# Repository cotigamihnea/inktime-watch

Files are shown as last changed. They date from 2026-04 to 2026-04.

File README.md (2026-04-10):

# InkTime Smartwatch - Proiect Hardware

Acesta este repository-ul oficial pentru dezvoltarea hardware a proiectului InkTime, un smartwatch bazat pe tehnologia E-Paper și procesorul nRF52840, optimizat pentru un consum redus de energie.

---

## 1. Diagramă Bloc

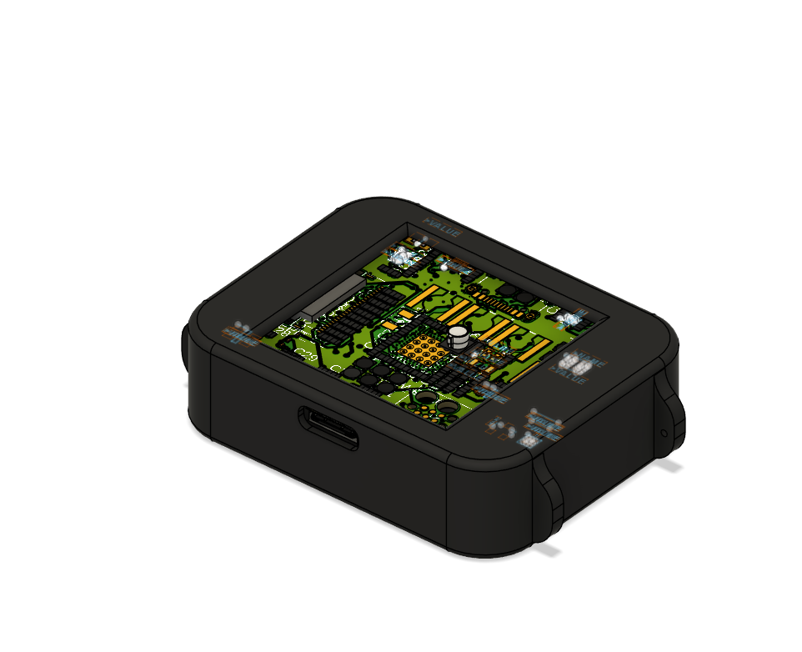
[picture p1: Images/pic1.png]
Diagrama Bloc


---

## 2. Bill of Materials (BOM) Principale

Mai jos sunt listate componentele integrate (IC) principale folosite în designul acestui smartwatch. Fișierul BOM complet cu toate componentele pasive (rezistențe, condensatoare) se găsește în folderul `Manufacturing`.

| Componentă / Modul | Rol în Sistem | JLC Parts Link | Datasheet |
| :--- | :--- | :--- | :--- |
| **nRF52840-QIAA** | Microcontroller Principal (BLE 5.0) | [C209930](https://jlcpcb.com/partdetail/Nordic_Semiconductor-nRF52840_QIAAR/C209930) | [Datasheet nRF52840](https://infocenter.nordicsemi.com/pdf/nRF52840_PS_v1.1.pdf) |
| **BQ25180YBGR** | Li-Ion Battery Charger (PMIC) | [C3005391](https://jlcpcb.com/partdetail/TexasInstruments-BQ25180YBGR/C3005391) | [Datasheet BQ25180](https://www.ti.com/lit/ds/symlink/bq25180.pdf) |
| **MAX17048G+T10** | Fuel Gauge (Monitorizare Baterie) | [C137599](https://jlcpcb.com/partdetail/Maxim_Integrated-MAX17048GT10/C137599) | [Datasheet MAX17048](https://datasheets.maximintegrated.com/en/ds/MAX17048-MAX17049.pdf) |
| **BMA421** | IMU / Accelerometru (Pedometer) | [C456073](https://jlcpcb.com/partdetail/Bosch-BMA421/C456073) | [Datasheet BMA421](https://www.bosch-sensortec.com/media/boschsensortec/downloads/datasheets/bst-bma421-fl000.pdf) |
| **503480-2400** | Conector Display E-Paper (24 pini) | [C265215](https://jlcpcb.com/partdetail/Molex-5034802400/C265215) | [Datasheet Molex](https://www.molex.com/pdm_docs/sd/5034802400_sd.pdf) |

---

## 3. Descrierea Funcționalității Hardware

Proiectul InkTime este gândit ca un wearable ultra-low-power. Arhitectura hardware este împărțită în următoarele module principale:

* **Unitatea de Procesare și Comunicație (nRF52840):** Este "creierul" plăcii. Acesta conține un nucleu ARM Cortex-M4F și un modul radio Bluetooth Low Energy (BLE 5.0). Microcontroller-ul gestionează toate perifericele și permite sincronizarea datelor cu un smartphone.
* **Afișajul (E-Paper Display):** Conectat printr-o interfață **SPI**, display-ul E-paper a fost ales pentru consumul său zero de energie în starea de repaus (consumă curent doar la refresh-ul ecranului). Circuitul său include o sursă de tensiune dedicată, cu o bobină și diode, comandată de un tranzistor DMG2305UX, pentru a-i asigura tensiunile specifice de operare.
* **Managementul Energiei (Power Management):** * **BQ25180:** Se ocupă de încărcarea sigură a bateriei Li-Po de la mufa USB (5V), setând curenți mici de încărcare adecvați bateriilor de smartwatch.
    * **MAX17048 (Fuel Gauge):** Citește tensiunea bateriei și calculează procentul (State of Charge - SoC) folosind algoritmul ModelGauge. Ambele comunică cu nRF-ul prin magistrala **I2C**.
* **Senzori și Haptic:** Accelerometrul **BMA421** este folosit pentru detectarea mișcării (ex: ridicarea mâinii pentru a aprinde ecranul) și numărarea pașilor, comunicând tot prin **I2C**. Pentru feedback tactil s-a integrat un driver haptic.
* **Considerații de Consum:** Designul este centrat pe eficiență. nRF52840 va sta majoritatea timpului în *Deep Sleep* (câțiva microamperi), trezindu-se doar la întreruperi generate de BMA421 (mișcare) sau la intervale regulate pentru a actualiza ecranul prin SPI.

---

## 4. Pinout nRF52840 (Alocarea Pinilor)

Microcontroller-ul comunică cu restul modulelor folosind interfețe digitale standardizate. Magistrala I2C este partajată pentru a economisi pini.

| Periferic / Modul | Pini nRF52840 Alocați | Interfață | Motiv / Funcție |
| :--- | :--- | :--- | :--- |
| **Magistrala I2C (Comună)** | `P0.11` (SDA), `P0.12` (SCL) | I2C | Folosită pentru BQ25180 (Charger), MAX17048 (Baterie) și BMA421 (IMU). I2C permite legarea mai multor senzori pe doar 2 pini fizici, reducând complexitatea rutării. |
| **BMA421 (Senzor Mișcare)**| `P0.13` (INT1) | GPIO | Pin de întrerupere pentru a „trezi” procesorul din sleep când utilizatorul face o mișcare bruscă. |
| **Display E-Paper** | `P1.01` (MOSI), `P1.02` (SCK), `P1.03` (CS) | SPI | Interfață de mare viteză unidirecțională pentru a trimite pixelii către ecran rapid. |
| **Control E-Paper** | `P1.04` (DC), `P1.05` (RST), `P1.06` (BUSY)| GPIO | Pini de control pentru stările ecranului (Data/Command, Reset și monitorizarea stării de Busy în timpul refresh-ului). |
| **Alimentare E-Paper** | `P0.06` | GPIO | Controlează tranzistorul care taie complet alimentarea ecranului când nu este folosit, salvând energie. |

*(Notă: Pinii exacți au fost aleși pentru a facilita cel mai scurt drum de rutare (Placement Optimization) pe PCB).*

---

## 5. Design Log & Renders

**Jurnal de Design:**
Proiectarea PCB-ului a presupus mai multe provocări:
1.  **Placement:** Componentele au fost grupate în "cartiere" logice: RF-ul sus în jurul antenei pentru a minimiza interferențele, IC-urile de Power Management lângă conectorul bateriei/USB, iar componentele digitale centralizate în jurul procesorului nRF52840.
2.  **Routing:** Datorită densității mari de pe o placă cu factor de formă mic (Smartwatch), am utilizat un mix de rutare manuală pentru traseele sensibile și Autorouter pentru optimizarea conexiunilor logice, obținând o rată de conectare excelentă pentru un sistem cu doar 2 straturi.

**Randări PCB:**
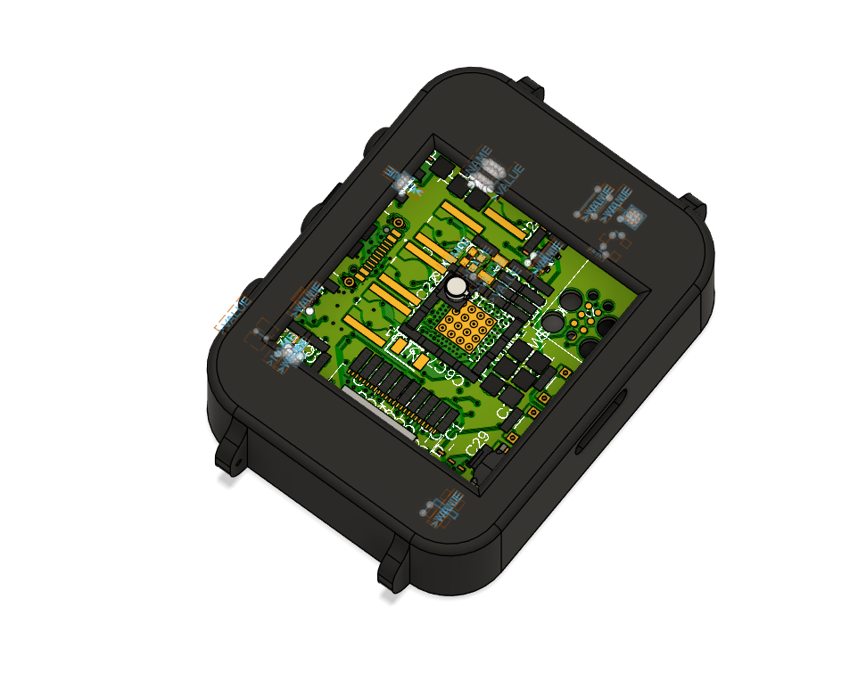
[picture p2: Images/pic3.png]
Top Render

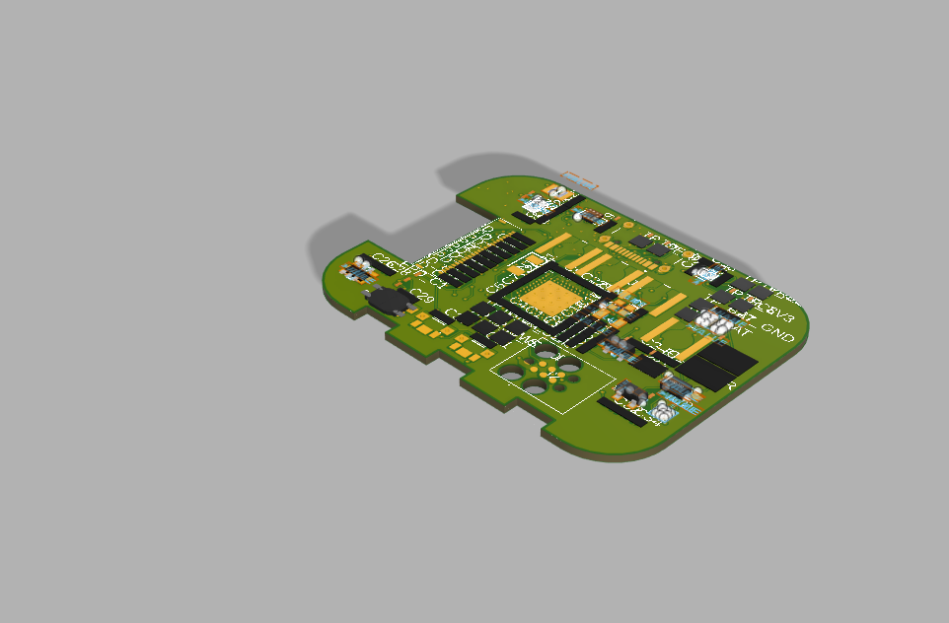
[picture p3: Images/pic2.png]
Bottom Render


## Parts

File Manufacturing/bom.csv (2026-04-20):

Part | Value | Device | Footprint Name | Detailed Description | ARROW_PART_NUMBER | ARROW_PRICE-STOCK | AVAILABILITY | CHECK_PRICES | COPYRIGHT | DESCRIPTION | DIGI-KEY_PART_NUMBER_1 | DIGI-KEY_PART_NUMBER_2 | DIGI-KEY_PART_NUMBER_3 | HEIGHT | JLCPCB | MANUFACTURER_NAME | MANUFACTURER_PART_NUMBER | MF | MFR_NAME | MOUSER_PART_NUMBER | MOUSER_PRICE-STOCK | MP | PACKAGE | POPULARITY | PRICE | PROD_ID | PURCHASE-URL | SNAPEDA_LINK | SPICEMODEL | SPICEPREFIX | TP_SIGNAL_NAME | VALUE
ANT1 | 2450AT18B100E_2450AT18B100E | 2450AT18B100E_2450AT18B100E | 2450AT18B100E_ANTC3216X140N | Antennas 2.45GHz ANTENNA | 2450AT18B100E | https://www.arrow.com/en/products/2450at18b100e/johanson-dielectrics?utm_currency=USD&region=nac |  |  |  | Antennas 2.45GHz ANTENNA |  |  |  | 1.4mm |  | JOHANSON TECHNOLOGY | 2450AT18B100E |  |  | 609-2450AT18B100E | https://www.mouser.co.uk/ProductDetail/Johanson-Technology/2450AT18B100E?qs=yCnrNFeXz%252Bh5MFsFIXGZGA%3D%3D
C1 | 12pF | ESP32_C6_LIBRARY_1_ESP32_WROVER_EAGLE-LTSPICE_CC0402 | ESP32_C6_LIBRARY_1_ESP32_WROVER_EAGLE-LTSPICE_C0402 | CAPACITOR, European symbol |  |  |  |  |  |  |  |  |  |  |  |  |  |  |  |  |  |  |  |  |  |  |  |  | NONE | C
C1-EP-DR | 10uF | ESP32_C6_LIBRARY_1_ESP32_WROVER_EAGLE-LTSPICE_CC0402 | ESP32_C6_LIBRARY_1_ESP32_WROVER_EAGLE-LTSPICE_C0402 | CAPACITOR, European symbol |  |  |  |  |  |  |  |  |  |  |  |  |  |  |  |  |  |  |  |  |  |  |  |  | NONE | C
C2 | 12pF | ESP32_C6_LIBRARY_1_ESP32_WROVER_EAGLE-LTSPICE_CC0402 | ESP32_C6_LIBRARY_1_ESP32_WROVER_EAGLE-LTSPICE_C0402 | CAPACITOR, European symbol |  |  |  |  |  |  |  |  |  |  |  |  |  |  |  |  |  |  |  |  |  |  |  |  | NONE | C
C2-EP-DR1 | 4.7uF/25V | ESP32_C6_LIBRARY_1_ESP32_WROVER_EAGLE-LTSPICE_CC0402 | ESP32_C6_LIBRARY_1_ESP32_WROVER_EAGLE-LTSPICE_C0402 | CAPACITOR, European symbol |  |  |  |  |  |  |  |  |  |  |  |  |  |  |  |  |  |  |  |  |  |  |  |  | NONE | C
C3 | 1pF | ESP32_C6_LIBRARY_1_ESP32_WROVER_EAGLE-LTSPICE_CC0402 | ESP32_C6_LIBRARY_1_ESP32_WROVER_EAGLE-LTSPICE_C0402 | CAPACITOR, European symbol |  |  |  |  |  |  |  |  |  |  |  |  |  |  |  |  |  |  |  |  |  |  |  |  | NONE | C
C4 | 1pF | ESP32_C6_LIBRARY_1_ESP32_WROVER_EAGLE-LTSPICE_CC0402 | ESP32_C6_LIBRARY_1_ESP32_WROVER_EAGLE-LTSPICE_C0402 | CAPACITOR, European symbol |  |  |  |  |  |  |  |  |  |  |  |  |  |  |  |  |  |  |  |  |  |  |  |  | NONE | C
C5 | 100nF | ESP32_C6_LIBRARY_1_ESP32_WROVER_EAGLE-LTSPICE_CC0402 | ESP32_C6_LIBRARY_1_ESP32_WROVER_EAGLE-LTSPICE_C0402 | CAPACITOR, European symbol |  |  |  |  |  |  |  |  |  |  |  |  |  |  |  |  |  |  |  |  |  |  |  |  | NONE | C
C6 | 4.7uF | ESP32_C6_LIBRARY_1_ESP32_WROVER_EAGLE-LTSPICE_CC0402 | ESP32_C6_LIBRARY_1_ESP32_WROVER_EAGLE-LTSPICE_C0402 | CAPACITOR, European symbol |  |  |  |  |  |  |  |  |  |  |  |  |  |  |  |  |  |  |  |  |  |  |  |  | NONE | C
C7 | 100nF | ESP32_C6_LIBRARY_1_ESP32_WROVER_EAGLE-LTSPICE_CC0402 | ESP32_C6_LIBRARY_1_ESP32_WROVER_EAGLE-LTSPICE_C0402 | CAPACITOR, European symbol |  |  |  |  |  |  |  |  |  |  |  |  |  |  |  |  |  |  |  |  |  |  |  |  | NONE | C
C8 | 100nF N.C. | ESP32_C6_LIBRARY_1_ESP32_WROVER_EAGLE-LTSPICE_CC0402 | ESP32_C6_LIBRARY_1_ESP32_WROVER_EAGLE-LTSPICE_C0402 | CAPACITOR, European symbol |  |  |  |  |  |  |  |  |  |  |  |  |  |  |  |  |  |  |  |  |  |  |  |  | NONE | C
C9 | 820pF | ESP32_C6_LIBRARY_1_ESP32_WROVER_EAGLE-LTSPICE_CC0402 | ESP32_C6_LIBRARY_1_ESP32_WROVER_EAGLE-LTSPICE_C0402 | CAPACITOR, European symbol |  |  |  |  |  |  |  |  |  |  |  |  |  |  |  |  |  |  |  |  |  |  |  |  | NONE | C
C10 | N.C. | ESP32_C6_LIBRARY_1_ESP32_WROVER_EAGLE-LTSPICE_CC0402 | ESP32_C6_LIBRARY_1_ESP32_WROVER_EAGLE-LTSPICE_C0402 | CAPACITOR, European symbol |  |  |  |  |  |  |  |  |  |  |  |  |  |  |  |  |  |  |  |  |  |  |  |  | NONE | C
C11 | 1pF | ESP32_C6_LIBRARY_1_ESP32_WROVER_EAGLE-LTSPICE_CC0402 | ESP32_C6_LIBRARY_1_ESP32_WROVER_EAGLE-LTSPICE_C0402 | CAPACITOR, European symbol |  |  |  |  |  |  |  |  |  |  |  |  |  |  |  |  |  |  |  |  |  |  |  |  | NONE | C
C12 | 100nF | ESP32_C6_LIBRARY_1_ESP32_WROVER_EAGLE-LTSPICE_CC0402 | ESP32_C6_LIBRARY_1_ESP32_WROVER_EAGLE-LTSPICE_C0402 | CAPACITOR, European symbol |  |  |  |  |  |  |  |  |  |  |  |  |  |  |  |  |  |  |  |  |  |  |  |  | NONE | C
C13 | N.C. | ESP32_C6_LIBRARY_1_ESP32_WROVER_EAGLE-LTSPICE_CC0402 | ESP32_C6_LIBRARY_1_ESP32_WROVER_EAGLE-LTSPICE_C0402 | CAPACITOR, European symbol |  |  |  |  |  |  |  |  |  |  |  |  |  |  |  |  |  |  |  |  |  |  |  |  | NONE | C
C14 | 4.7uF | ESP32_C6_LIBRARY_1_ESP32_WROVER_EAGLE-LTSPICE_CC0402 | ESP32_C6_LIBRARY_1_ESP32_WROVER_EAGLE-LTSPICE_C0402 | CAPACITOR, European symbol |  |  |  |  |  |  |  |  |  |  |  |  |  |  |  |  |  |  |  |  |  |  |  |  | NONE | C
C15 | 1.0uF | ESP32_C6_LIBRARY_1_ESP32_WROVER_EAGLE-LTSPICE_CC0402 | ESP32_C6_LIBRARY_1_ESP32_WROVER_EAGLE-LTSPICE_C0402 | CAPACITOR, European symbol |  |  |  |  |  |  |  |  |  |  |  |  |  |  |  |  |  |  |  |  |  |  |  |  | NONE | C
C16 | 47nF | ESP32_C6_LIBRARY_1_ESP32_WROVER_EAGLE-LTSPICE_CC0402 | ESP32_C6_LIBRARY_1_ESP32_WROVER_EAGLE-LTSPICE_C0402 | CAPACITOR, European symbol |  |  |  |  |  |  |  |  |  |  |  |  |  |  |  |  |  |  |  |  |  |  |  |  | NONE | C
C17 | 12pF | ESP32_C6_LIBRARY_1_ESP32_WROVER_EAGLE-LTSPICE_CC0402 | ESP32_C6_LIBRARY_1_ESP32_WROVER_EAGLE-LTSPICE_C0402 | CAPACITOR, European symbol |  |  |  |  |  |  |  |  |  |  |  |  |  |  |  |  |  |  |  |  |  |  |  |  | NONE | C
C18 | 12pF | ESP32_C6_LIBRARY_1_ESP32_WROVER_EAGLE-LTSPICE_CC0402 | ESP32_C6_LIBRARY_1_ESP32_WROVER_EAGLE-LTSPICE_C0402 | CAPACITOR, European symbol |  |  |  |  |  |  |  |  |  |  |  |  |  |  |  |  |  |  |  |  |  |  |  |  | NONE | C
C19 | 22uF | ESP32_C6_LIBRARY_1_ESP32_WROVER_EAGLE-LTSPICE_CC0402 | ESP32_C6_LIBRARY_1_ESP32_WROVER_EAGLE-LTSPICE_C0402 | CAPACITOR, European symbol |  |  |  |  |  |  |  |  |  |  |  |  |  |  |  |  |  |  |  |  |  |  |  |  | NONE | C
C20 | 4.7uF | ESP32_C6_LIBRARY_1_ESP32_WROVER_EAGLE-LTSPICE_CC0402 | ESP32_C6_LIBRARY_1_ESP32_WROVER_EAGLE-LTSPICE_C0402 | CAPACITOR, European symbol |  |  |  |  |  |  |  |  |  |  |  |  |  |  |  |  |  |  |  |  |  |  |  |  | NONE | C
C21 | 4.7uF | ESP32_C6_LIBRARY_1_ESP32_WROVER_EAGLE-LTSPICE_CC0402 | ESP32_C6_LIBRARY_1_ESP32_WROVER_EAGLE-LTSPICE_C0402 | CAPACITOR, European symbol |  |  |  |  |  |  |  |  |  |  |  |  |  |  |  |  |  |  |  |  |  |  |  |  | NONE | C
C22 | N.C. | ESP32_C6_LIBRARY_1_ESP32_WROVER_EAGLE-LTSPICE_CC0402 | ESP32_C6_LIBRARY_1_ESP32_WROVER_EAGLE-LTSPICE_C0402 | CAPACITOR, European symbol |  |  |  |  |  |  |  |  |  |  |  |  |  |  |  |  |  |  |  |  |  |  |  |  | NONE | C
C23 | 0.1uF | ESP32_C6_LIBRARY_1_ESP32_WROVER_EAGLE-LTSPICE_CC0402 | ESP32_C6_LIBRARY_1_ESP32_WROVER_EAGLE-LTSPICE_C0402 | CAPACITOR, European symbol |  |  |  |  |  |  |  |  |  |  |  |  |  |  |  |  |  |  |  |  |  |  |  |  | NONE | C
C24 | 10uF | ESP32_C6_LIBRARY_1_ESP32_WROVER_EAGLE-LTSPICE_CC0402 | ESP32_C6_LIBRARY_1_ESP32_WROVER_EAGLE-LTSPICE_C0402 | CAPACITOR, European symbol |  |  |  |  |  |  |  |  |  |  |  |  |  |  |  |  |  |  |  |  |  |  |  |  | NONE | C
C25 | 22uF | ESP32_C6_LIBRARY_1_ESP32_WROVER_EAGLE-LTSPICE_CC0402 | ESP32_C6_LIBRARY_1_ESP32_WROVER_EAGLE-LTSPICE_C0402 | CAPACITOR, European symbol |  |  |  |  |  |  |  |  |  |  |  |  |  |  |  |  |  |  |  |  |  |  |  |  | NONE | C
C26 | 820pF | ESP32_C6_LIBRARY_1_ESP32_WROVER_EAGLE-LTSPICE_CC0402 | ESP32_C6_LIBRARY_1_ESP32_WROVER_EAGLE-LTSPICE_C0402 | CAPACITOR, European symbol |  |  |  |  |  |  |  |  |  |  |  |  |  |  |  |  |  |  |  |  |  |  |  |  | NONE | C
C27 | 0.1uF | ESP32_C6_LIBRARY_1_ESP32_WROVER_EAGLE-LTSPICE_CC0402 | ESP32_C6_LIBRARY_1_ESP32_WROVER_EAGLE-LTSPICE_C0402 | CAPACITOR, European symbol |  |  |  |  |  |  |  |  |  |  |  |  |  |  |  |  |  |  |  |  |  |  |  |  | NONE | C
C28 | 820pF | ESP32_C6_LIBRARY_1_ESP32_WROVER_EAGLE-LTSPICE_CC0402 | ESP32_C6_LIBRARY_1_ESP32_WROVER_EAGLE-LTSPICE_C0402 | CAPACITOR, European symbol |  |  |  |  |  |  |  |  |  |  |  |  |  |  |  |  |  |  |  |  |  |  |  |  | NONE | C
C29 | 1uF | ESP32_C6_LIBRARY_1_ESP32_WROVER_EAGLE-LTSPICE_CC0402 | ESP32_C6_LIBRARY_1_ESP32_WROVER_EAGLE-LTSPICE_C0402 | CAPACITOR, European symbol |  |  |  |  |  |  |  |  |  |  |  |  |  |  |  |  |  |  |  |  |  |  |  |  | NONE | C
C30 | 1uF | ESP32_C6_LIBRARY_1_ESP32_WROVER_EAGLE-LTSPICE_CC0402 | ESP32_C6_LIBRARY_1_ESP32_WROVER_EAGLE-LTSPICE_C0402 | CAPACITOR, European symbol |  |  |  |  |  |  |  |  |  |  |  |  |  |  |  |  |  |  |  |  |  |  |  |  | NONE | C
C31 | 1uF | ESP32_C6_LIBRARY_1_ESP32_WROVER_EAGLE-LTSPICE_CC0402 | ESP32_C6_LIBRARY_1_ESP32_WROVER_EAGLE-LTSPICE_C0402 | CAPACITOR, European symbol |  |  |  |  |  |  |  |  |  |  |  |  |  |  |  |  |  |  |  |  |  |  |  |  | NONE | C
C32 | 1uF | ESP32_C6_LIBRARY_1_ESP32_WROVER_EAGLE-LTSPICE_CC0402 | ESP32_C6_LIBRARY_1_ESP32_WROVER_EAGLE-LTSPICE_C0402 | CAPACITOR, European symbol |  |  |  |  |  |  |  |  |  |  |  |  |  |  |  |  |  |  |  |  |  |  |  |  | NONE | C
C33 | 22uF | ESP32_C6_LIBRARY_1_ESP32_WROVER_EAGLE-LTSPICE_CC0402 | ESP32_C6_LIBRARY_1_ESP32_WROVER_EAGLE-LTSPICE_C0402 | CAPACITOR, European symbol |  |  |  |  |  |  |  |  |  |  |  |  |  |  |  |  |  |  |  |  |  |  |  |  | NONE | C
C34 | 0.1uF | ESP32_C6_LIBRARY_1_ESP32_WROVER_EAGLE-LTSPICE_CC0402 | ESP32_C6_LIBRARY_1_ESP32_WROVER_EAGLE-LTSPICE_C0402 | CAPACITOR, European symbol |  |  |  |  |  |  |  |  |  |  |  |  |  |  |  |  |  |  |  |  |  |  |  |  | NONE | C
C37 | 1uF | ESP32_C6_LIBRARY_1_ESP32_WROVER_EAGLE-LTSPICE_CC0402 | ESP32_C6_LIBRARY_1_ESP32_WROVER_EAGLE-LTSPICE_C0402 | CAPACITOR, European symbol |  |  |  |  |  |  |  |  |  |  |  |  |  |  |  |  |  |  |  |  |  |  |  |  | NONE | C
C38 | 1uF | ESP32_C6_LIBRARY_1_ESP32_WROVER_EAGLE-LTSPICE_CC0402 | ESP32_C6_LIBRARY_1_ESP32_WROVER_EAGLE-LTSPICE_C0402 | CAPACITOR, European symbol |  |  |  |  |  |  |  |  |  |  |  |  |  |  |  |  |  |  |  |  |  |  |  |  | NONE | C
C39 | 10uF | ESP32_C6_LIBRARY_1_ESP32_WROVER_EAGLE-LTSPICE_CC0402 | ESP32_C6_LIBRARY_1_ESP32_WROVER_EAGLE-LTSPICE_C0402 | CAPACITOR, European symbol |  |  |  |  |  |  |  |  |  |  |  |  |  |  |  |  |  |  |  |  |  |  |  |  | NONE | C
D2 | ESP32_C6_LIBRARY_5_MBR0530 | ESP32_C6_LIBRARY_5_MBR0530 | ESP32_C6_LIBRARY_5_SOD3716X135N | ON SEMICONDUCTOR - MBR0530 - DIODE, SCHOTTKY, 0.5A, 30V, SOD-123 |  |  | In Stock | https://www.snapeda.com/parts/MBR0530/Onsemi/view-part/?ref=eda |  | Diode Schottky 30 V 500mA Surface Mount SOD-123 |  |  |  |  |  |  |  | ON Semiconductor |  |  |  | MBR0530 | SOD-123-2 ON Semiconductor |  | None |  | https://www.snapeda.com/api/url_track_click_mouser/?unipart_id=179458&manufacturer=ON Semiconductor&part_name=MBR0530&search_term=None | https://www.snapeda.com/parts/MBR0530/Onsemi/view-part/?ref=snap
D3 | ESP32_C6_LIBRARY_3_USBLC6-2SC6Y | ESP32_C6_LIBRARY_3_USBLC6-2SC6Y | ESP32_C6_LIBRARY_3_SOT95P280X145-6N | Low Cap. ESD Protection Auto SOT-23-6 STMicroelectronics USBLC6-2SC6Y, Dual Uni-Directional TVS Diode Array, 6-Pin SOT-23 |  |  | In Stock | https://www.snapeda.com/parts/USBLC6-2SC6Y/STMicroelectronics/view-part/?ref=eda |  | 17V Clamp 5A (8/20µs) Ipp Tvs Diode Surface Mount SOT-23-6 |  |  |  |  |  |  |  | STMicroelectronics |  |  |  | USBLC6-2SC6Y | SOT-23-6 STMicroelectronics |  | None |  |  | https://www.snapeda.com/parts/USBLC6-2SC6Y/STMicroelectronics/view-part/?ref=snap
D4 | ESP32_C6_LIBRARY_5_MBR0530 | ESP32_C6_LIBRARY_5_MBR0530 | ESP32_C6_LIBRARY_5_SOD3716X135N | ON SEMICONDUCTOR - MBR0530 - DIODE, SCHOTTKY, 0.5A, 30V, SOD-123 |  |  | In Stock | https://www.snapeda.com/parts/MBR0530/Onsemi/view-part/?ref=eda |  | Diode Schottky 30 V 500mA Surface Mount SOD-123 |  |  |  |  |  |  |  | ON Semiconductor |  |  |  | MBR0530 | SOD-123-2 ON Semiconductor |  | None |  | https://www.snapeda.com/api/url_track_click_mouser/?unipart_id=179458&manufacturer=ON Semiconductor&part_name=MBR0530&search_term=None | https://www.snapeda.com/parts/MBR0530/Onsemi/view-part/?ref=snap
D5 | ESP32_C6_LIBRARY_5_MBR0530 | ESP32_C6_LIBRARY_5_MBR0530 | ESP32_C6_LIBRARY_5_SOD3716X135N | ON SEMICONDUCTOR - MBR0530 - DIODE, SCHOTTKY, 0.5A, 30V, SOD-123 |  |  | In Stock | https://www.snapeda.com/parts/MBR0530/Onsemi/view-part/?ref=eda |  | Diode Schottky 30 V 500mA Surface Mount SOD-123 |  |  |  |  |  |  |  | ON Semiconductor |  |  |  | MBR0530 | SOD-123-2 ON Semiconductor |  | None |  | https://www.snapeda.com/api/url_track_click_mouser/?unipart_id=179458&manufacturer=ON Semiconductor&part_name=MBR0530&search_term=None | https://www.snapeda.com/parts/MBR0530/Onsemi/view-part/?ref=snap
EPD_C1 | 1uF/50V | ESP32_C6_LIBRARY_1_ESP32_WROVER_EAGLE-LTSPICE_CC0402 | ESP32_C6_LIBRARY_1_ESP32_WROVER_EAGLE-LTSPICE_C0402 | CAPACITOR, European symbol |  |  |  |  |  |  |  |  |  |  |  |  |  |  |  |  |  |  |  |  |  |  |  |  | NONE | C
EPD_C2 | 1uF/50V | ESP32_C6_LIBRARY_1_ESP32_WROVER_EAGLE-LTSPICE_CC0402 | ESP32_C6_LIBRARY_1_ESP32_WROVER_EAGLE-LTSPICE_C0402 | CAPACITOR, European symbol |  |  |  |  |  |  |  |  |  |  |  |  |  |  |  |  |  |  |  |  |  |  |  |  | NONE | C
EPD_C5 | 0.1uF/50V | ESP32_C6_LIBRARY_1_ESP32_WROVER_EAGLE-LTSPICE_CC0402 | ESP32_C6_LIBRARY_1_ESP32_WROVER_EAGLE-LTSPICE_C0402 | CAPACITOR, European symbol |  |  |  |  |  |  |  |  |  |  |  |  |  |  |  |  |  |  |  |  |  |  |  |  | NONE | C
EPD_C6 | 1uF/50V | ESP32_C6_LIBRARY_1_ESP32_WROVER_EAGLE-LTSPICE_CC0402 | ESP32_C6_LIBRARY_1_ESP32_WROVER_EAGLE-LTSPICE_C0402 | CAPACITOR, European symbol |  |  |  |  |  |  |  |  |  |  |  |  |  |  |  |  |  |  |  |  |  |  |  |  | NONE | C
EPD_C7 | 1uF/50V | ESP32_C6_LIBRARY_1_ESP32_WROVER_EAGLE-LTSPICE_CC0402 | ESP32_C6_LIBRARY_1_ESP32_WROVER_EAGLE-LTSPICE_C0402 | CAPACITOR, European symbol |  |  |  |  |  |  |  |  |  |  |  |  |  |  |  |  |  |  |  |  |  |  |  |  | NONE | C
EPD_C8 | 1uF/50V | ESP32_C6_LIBRARY_1_ESP32_WROVER_EAGLE-LTSPICE_CC0402 | ESP32_C6_LIBRARY_1_ESP32_WROVER_EAGLE-LTSPICE_C0402 | CAPACITOR, European symbol |  |  |  |  |  |  |  |  |  |  |  |  |  |  |  |  |  |  |  |  |  |  |  |  | NONE | C
EPD_C9 | 1uF/50V | ESP32_C6_LIBRARY_1_ESP32_WROVER_EAGLE-LTSPICE_CC0402 | ESP32_C6_LIBRARY_1_ESP32_WROVER_EAGLE-LTSPICE_C0402 | CAPACITOR, European symbol |  |  |  |  |  |  |  |  |  |  |  |  |  |  |  |  |  |  |  |  |  |  |  |  | NONE | C
EPD_C10 | 1uF/50V | ESP32_C6_LIBRARY_1_ESP32_WROVER_EAGLE-LTSPICE_CC0402 | ESP32_C6_LIBRARY_1_ESP32_WROVER_EAGLE-LTSPICE_C0402 | CAPACITOR, European symbol |  |  |  |  |  |  |  |  |  |  |  |  |  |  |  |  |  |  |  |  |  |  |  |  | NONE | C
EPD_C11 | 1uF/50V | ESP32_C6_LIBRARY_1_ESP32_WROVER_EAGLE-LTSPICE_CC0402 | ESP32_C6_LIBRARY_1_ESP32_WROVER_EAGLE-LTSPICE_C0402 | CAPACITOR, European symbol |  |  |  |  |  |  |  |  |  |  |  |  |  |  |  |  |  |  |  |  |  |  |  |  | NONE | C
EPD_C12 | 1uF/50V | ESP32_C6_LIBRARY_1_ESP32_WROVER_EAGLE-LTSPICE_CC0402 | ESP32_C6_LIBRARY_1_ESP32_WROVER_EAGLE-LTSPICE_C0402 | CAPACITOR, European symbol |  |  |  |  |  |  |  |  |  |  |  |  |  |  |  |  |  |  |  |  |  |  |  |  | NONE | C
IC1 | BQ25180YBGR_BQ25180YBGR | BQ25180YBGR_BQ25180YBGR | BQ25180YBGR_BGA8C40P2X4_100X155X50 | Charger IC Lithium Ion/Polymer, Lithium Iron Phosphate 8-DSBGA (1.6x1.1) | BQ25180YBGR | https://www.arrow.com/en/products/bq25180ybgr/texas-instruments?utm_currency=USD&region=nac |  |  |  | Charger IC Lithium Ion/Polymer, Lithium Iron Phosphate 8-DSBGA (1.6x1.1) |  |  |  | 0.5mm |  | Texas Instruments | BQ25180YBGR |  |  | 595-BQ25180YBGR | https://www.mouser.co.uk/ProductDetail/Texas-Instruments/BQ25180YBGR?qs=doiCPypUmgEWjAK%252BJAX6Tw%3D%3D
IC2 | DRV2605YZFR_DRV2605YZFR | DRV2605YZFR_DRV2605YZFR | DRV2605YZFR_BGA9C50P3X3_144X144X62 | Haptic Driver for ERM/LRA with Built-In Library and Smart Loop Architecture | DRV2605YZFR | https://www.arrow.com/en/products/drv2605yzfr/texas-instruments?region=nac |  |  |  | Haptic Driver for ERM/LRA with Built-In Library and Smart Loop Architecture |  |  |  | 0.625mm |  | Texas Instruments | DRV2605YZFR
IC3 | BMA423_BMA423 | BMA423_BMA423 | BMA423_BMA423 | Accelerometers Triaxial low-g 12bit Acceleration Sensor | BMA423 | https://www.arrow.com/en/products/bma423/bosch |  |  |  | Accelerometers Triaxial low-g 12bit Acceleration Sensor |  |  |  | 1mm |  | BOSCH | BMA423 |  |  | 262-BMA423 | https://www.mouser.co.uk/ProductDetail/Bosch-Sensortec/BMA423?qs=HXFqYaX1Q2xC%252BSgeGoX3mg%3D%3D
IC9 | RT6160AWSC_RT6160AWSC | RT6160AWSC_RT6160AWSC | RT6160AWSC_BGA15C40P3X5_140X230X60 | Buck-Boost Regulator Positive Output Step-Up/Step-Down I2C DC-DC Controller IC 15-WL-CSP (BSC) (1.4x2.3) |  |  |  |  |  | Buck-Boost Regulator Positive Output Step-Up/Step-Down I2C DC-DC Controller IC 15-WL-CSP (BSC) (1.4x2.3) |  |  |  | 0.6mm |  | RICHTEK | RT6160AWSC |  |  | 835-RT6160AWSC | https://www.mouser.co.uk/ProductDetail/Richtek/RT6160AWSC?qs=amGC7iS6iy%2FLd9PSoixZXQ%3D%3D
J1 | 503480-2400_503480-2400 | 503480-2400_503480-2400 | 503480-2400_5034802400 | FFC & FPC Connectors 0.5mm FPC RA SMT Dual Contact 24Ckt |  |  |  |  |  | FFC & FPC Connectors 0.5mm FPC RA SMT Dual Contact 24Ckt |  |  |  | 1.87mm |  | Molex | 503480-2400 |  |  | 538-503480-2400 | https://www.mouser.co.uk/ProductDetail/Molex/503480-2400?qs=OAhjpuo3Vu7efIoxFh9AOw%3D%3D
J2 | TC2030-IDC_TC2030-IDC | TC2030-IDC_TC2030-IDC | TC2030-IDC_TC2030IDC | CABLE ADAPTER 6 POS |  |  |  |  |  | CABLE ADAPTER 6 POS |  |  |  | 19mm |  | Tag Connect | TC2030-IDC
J4 | KH-TYPE-C-16P_KH-TYPE-C-16P | KH-TYPE-C-16P_KH-TYPE-C-16P | KH-TYPE-C-16P_KINGHELM_KH-TYPE-C-16P | Check availability |  |  | Not in stock | https://www.snapeda.com/parts/KH-TYPE-C-16P/Kinghelm/view-part/?ref=eda |  |  |  |  |  |  |  |  |  | kinghelm |  |  |  | KH-TYPE-C-16P | None |  | None |  |  | https://www.snapeda.com/parts/KH-TYPE-C-16P/Kinghelm/view-part/?ref=snap
L1 | 3.9nH | ESP32_C6_LIBRARY_2_744043680IND_4828-WE-TPC_WRE | ESP32_C6_LIBRARY_2_IND_4828-WE-TPC_WRE |  |  |  |  |  | Copyright (C) 2024 Ultra Librarian. All rights reserved. |  |  |  |  |  |  |  | 744043680 |  | Wurth Electronics
L2 | 10uH | ESP32_C6_LIBRARY_2_744043680IND_4828-WE-TPC_WRE | ESP32_C6_LIBRARY_2_IND_4828-WE-TPC_WRE |  |  |  |  |  | Copyright (C) 2024 Ultra Librarian. All rights reserved. |  |  |  |  |  |  |  | 744043680 |  | Wurth Electronics
L3 | 15nH | ESP32_C6_LIBRARY_2_744043680IND_4828-WE-TPC_WRE | ESP32_C6_LIBRARY_2_IND_4828-WE-TPC_WRE |  |  |  |  |  | Copyright (C) 2024 Ultra Librarian. All rights reserved. |  |  |  |  |  |  |  | 744043680 |  | Wurth Electronics
L5 | 68uH | ESP32_C6_LIBRARY_2_744043680IND_4828-WE-TPC_WRE | ESP32_C6_LIBRARY_2_IND_4828-WE-TPC_WRE |  |  |  |  |  | Copyright (C) 2024 Ultra Librarian. All rights reserved. |  |  |  |  |  |  |  | 744043680 |  | Wurth Electronics
L7 | MLP2016SR47MT0S1_FTC252012SR47MBCA | MLP2016SR47MT0S1_FTC252012SR47MBCA | MLP2016SR47MT0S1_INDC2016X100N | SMD / SMT Inductors (Coils), L=0.47?H, L x W x T : |  |  |  |  |  | SMD / SMT Inductors (Coils), L=0.47?H, L x W x T : |  |  |  | 1mm | https://jlcpcb.com/partdetail/6763488-FTC252012SR47MBCA/C5832368 | TDK | FTC252012SR47MBCA
Q1 | 20V/4.2A/52mO/1.4W | ESP32_C6_LIBRARY_4_ESP32_WROVER_SPARKFUN-DISCRETESEMI_MOSFET_PCH-DMG2305UX-7 | ESP32_C6_LIBRARY_4_ESP32_C6_LIBRARY_4_ESP32_C6_LIBRARY_4_ESP32_C6_LIBRARY_4_ESP32_WROVER_SPARKFUN-DISCRETESEMI_SOT23-3 | P-channel MOSFETs |  |  |  |  |  |  |  |  |  |  |  |  |  |  |  |  |  |  |  |  |  | TRAN-14388 |  |  |  |  |  | 20V/4.2A/52mO/1.4W
Q3 | ESP32_C6_LIBRARY_6_SI1308EDL-T1-GE3 | ESP32_C6_LIBRARY_6_SI1308EDL-T1-GE3 | ESP32_C6_LIBRARY_6_SOT65P210X110-3N | MOSFET N-Ch 30V 1.5A TrenchFET SC70 Vishay Si1308EDL-T1-GE3 N-channel MOSFET Transistor, 1.5 A, 30 V, 3-Pin SC-70 |  |  | In Stock | https://www.snapeda.com/parts/SI1308EDL-T1-GE3/Vishay+Siliconix/view-part/?ref=eda |  | Si1308EDL-T1-GE3 N-channel MOSFET Transistor, 1.5 A, 30 V, 3-Pin SC-70 | Siliconix / Vishay SI1308EDL-T1-GE3 |  |  |  |  |  |  |  | Vishay Siliconix |  |  |  | SI1308EDL-T1-GE3 | SOT-323 Vishay Semiconductor |  | None |  | https://www.snapeda.com/api/url_track_click_mouser/?unipart_id=274603&manufacturer=Vishay Siliconix&part_name=SI1308EDL-T1-GE3&search_term=None | https://www.snapeda.com/parts/SI1308EDL-T1-GE3/Vishay+Siliconix/view-part/?ref=snap
R1 | 10K | CPF0201D7K68C1_CPF0201D7K68C1 | CPF0201D7K68C1_0201 | 7.68k 0201 Thin Film Surface Mount Fixed Resistor +/-0.5% 0.031W CPF0201D7K68C1
R1_EP_DR | 0.47 | CPF0201D7K68C1_CPF0201D7K68C1 | CPF0201D7K68C1_0201 | 7.68k 0201 Thin Film Surface Mount Fixed Resistor +/-0.5% 0.031W CPF0201D7K68C1
R1_USB | 5K1 | CPF0201D7K68C1_CPF0201D7K68C1 | CPF0201D7K68C1_0201 | 7.68k 0201 Thin Film Surface Mount Fixed Resistor +/-0.5% 0.031W CPF0201D7K68C1
R2 | 0 | CPF0201D7K68C1_CPF0201D7K68C1 | CPF0201D7K68C1_0201 | 7.68k 0201 Thin Film Surface Mount Fixed Resistor +/-0.5% 0.031W CPF0201D7K68C1
R2_EP_DR | 10K | CPF0201D7K68C1_CPF0201D7K68C1 | CPF0201D7K68C1_0201 | 7.68k 0201 Thin Film Surface Mount Fixed Resistor +/-0.5% 0.031W CPF0201D7K68C1
R2_USB | 5K1 | CPF0201D7K68C1_CPF0201D7K68C1 | CPF0201D7K68C1_0201 | 7.68k 0201 Thin Film Surface Mount Fixed Resistor +/-0.5% 0.031W CPF0201D7K68C1
R3 | 0 | CPF0201D7K68C1_CPF0201D7K68C1 | CPF0201D7K68C1_0201 | 7.68k 0201 Thin Film Surface Mount Fixed Resistor +/-0.5% 0.031W CPF0201D7K68C1
R4 | 0 | CPF0201D7K68C1_CPF0201D7K68C1 | CPF0201D7K68C1_0201 | 7.68k 0201 Thin Film Surface Mount Fixed Resistor +/-0.5% 0.031W CPF0201D7K68C1
R5 | 10K | CPF0201D7K68C1_CPF0201D7K68C1 | CPF0201D7K68C1_0201 | 7.68k 0201 Thin Film Surface Mount Fixed Resistor +/-0.5% 0.031W CPF0201D7K68C1
R7 | 10K | CPF0201D7K68C1_CPF0201D7K68C1 | CPF0201D7K68C1_0201 | 7.68k 0201 Thin Film Surface Mount Fixed Resistor +/-0.5% 0.031W CPF0201D7K68C1
R8 | 10K | CPF0201D7K68C1_CPF0201D7K68C1 | CPF0201D7K68C1_0201 | 7.68k 0201 Thin Film Surface Mount Fixed Resistor +/-0.5% 0.031W CPF0201D7K68C1
R17 | 3K3 | CPF0201D7K68C1_CPF0201D7K68C1 | CPF0201D7K68C1_0201 | 7.68k 0201 Thin Film Surface Mount Fixed Resistor +/-0.5% 0.031W CPF0201D7K68C1
R18 | 3K3 | CPF0201D7K68C1_CPF0201D7K68C1 | CPF0201D7K68C1_0201 | 7.68k 0201 Thin Film Surface Mount Fixed Resistor +/-0.5% 0.031W CPF0201D7K68C1
R_PWR_EPD | 10K | CPF0201D7K68C1_CPF0201D7K68C1 | CPF0201D7K68C1_0201 | 7.68k 0201 Thin Film Surface Mount Fixed Resistor +/-0.5% 0.031W CPF0201D7K68C1
R_TYPE_SEL | 2.2 | CPF0201D7K68C1_CPF0201D7K68C1 | CPF0201D7K68C1_0201 | 7.68k 0201 Thin Film Surface Mount Fixed Resistor +/-0.5% 0.031W CPF0201D7K68C1
SJ1 |  | ESP32_C6_LIBRARY_7_JUMPER_SJ | ESP32_C6_LIBRARY_7_JUMPER_SJ | SMD solder JUMPER |  |  |  |  |  |  |  |  |  |  |  |  |  |  |  |  |  |  |  | 3
SW_DN | 2025-10-22_07-23-44_LIBRARY_EVP-AKE31ASW_EVP-AKE31A_PAN | 2025-10-22_07-23-44_LIBRARY_EVP-AKE31ASW_EVP-AKE31A_PAN | 2025-10-22_07-23-44_LIBRARY_SW_EVP-AKE31A_PAN |  |  |  |  |  | Copyright (C) 2025 Ultra Librarian. All rights reserved. |  | P123437TR-ND | P123437CT-ND | P123437DKR-ND |  |  | Panasonic | EVP-AKE31A
SW_ENT | 2025-10-22_07-23-44_LIBRARY_EVP-AKE31ASW_EVP-AKE31A_PAN | 2025-10-22_07-23-44_LIBRARY_EVP-AKE31ASW_EVP-AKE31A_PAN | 2025-10-22_07-23-44_LIBRARY_SW_EVP-AKE31A_PAN |  |  |  |  |  | Copyright (C) 2025 Ultra Librarian. All rights reserved. |  | P123437TR-ND | P123437CT-ND | P123437DKR-ND |  |  | Panasonic | EVP-AKE31A
SW_UP | 2025-10-22_07-23-44_LIBRARY_EVP-AKE31ASW_EVP-AKE31A_PAN | 2025-10-22_07-23-44_LIBRARY_EVP-AKE31ASW_EVP-AKE31A_PAN | 2025-10-22_07-23-44_LIBRARY_SW_EVP-AKE31A_PAN |  |  |  |  |  | Copyright (C) 2025 Ultra Librarian. All rights reserved. |  | P123437TR-ND | P123437CT-ND | P123437DKR-ND |  |  | Panasonic | EVP-AKE31A
TP_3.3V | HECTOR_WATCH_1_TPTP20R | HECTOR_WATCH_1_TPTP20R | HECTOR_WATCH_1_TP20R | Test pad |  |  |  |  |  |  |  |  |  |  |  |  |  |  |  |  |  |  |  | 2
TP_3V3 | HECTOR_WATCH_1_TPTP20R | HECTOR_WATCH_1_TPTP20R | HECTOR_WATCH_1_TP20R | Test pad |  |  |  |  |  |  |  |  |  |  |  |  |  |  |  |  |  |  |  | 2
TP_BAT_GND | HECTOR_WATCH_1_TPTP20R | HECTOR_WATCH_1_TPTP20R | HECTOR_WATCH_1_TP20R | Test pad |  |  |  |  |  |  |  |  |  |  |  |  |  |  |  |  |  |  |  | 2
TP_GND | HECTOR_WATCH_1_TPTP20R | HECTOR_WATCH_1_TPTP20R | HECTOR_WATCH_1_TP20R | Test pad |  |  |  |  |  |  |  |  |  |  |  |  |  |  |  |  |  |  |  | 2
TP_OFF | HECTOR_WATCH_1_TPTP20R | HECTOR_WATCH_1_TPTP20R | HECTOR_WATCH_1_TP20R | Test pad |  |  |  |  |  |  |  |  |  |  |  |  |  |  |  |  |  |  |  | 2
TP_ON | HECTOR_WATCH_1_TPTP20R | HECTOR_WATCH_1_TPTP20R | HECTOR_WATCH_1_TP20R | Test pad |  |  |  |  |  |  |  |  |  |  |  |  |  |  |  |  |  |  |  | 2
TP_RESET | HECTOR_WATCH_1_TPTP20R | HECTOR_WATCH_1_TPTP20R | HECTOR_WATCH_1_TP20R | Test pad |  |  |  |  |  |  |  |  |  |  |  |  |  |  |  |  |  |  |  | 2
TP_SCL | HECTOR_WATCH_1_TPTP20R | HECTOR_WATCH_1_TPTP20R | HECTOR_WATCH_1_TP20R | Test pad |  |  |  |  |  |  |  |  |  |  |  |  |  |  |  |  |  |  |  | 2
TP_SDA | HECTOR_WATCH_1_TPTP20R | HECTOR_WATCH_1_TPTP20R | HECTOR_WATCH_1_TP20R | Test pad |  |  |  |  |  |  |  |  |  |  |  |  |  |  |  |  |  |  |  | 2
TP_SWDCLK | HECTOR_WATCH_1_TPTP20R | HECTOR_WATCH_1_TPTP20R | HECTOR_WATCH_1_TP20R | Test pad |  |  |  |  |  |  |  |  |  |  |  |  |  |  |  |  |  |  |  | 2
TP_SWDIO | HECTOR_WATCH_1_TPTP20R | HECTOR_WATCH_1_TPTP20R | HECTOR_WATCH_1_TP20R | Test pad |  |  |  |  |  |  |  |  |  |  |  |  |  |  |  |  |  |  |  | 2
TP_SWO | HECTOR_WATCH_1_TPTP20R | HECTOR_WATCH_1_TPTP20R | HECTOR_WATCH_1_TP20R | Test pad |  |  |  |  |  |  |  |  |  |  |  |  |  |  |  |  |  |  |  | 2
TP_VBAT | HECTOR_WATCH_1_TPTP20R | HECTOR_WATCH_1_TPTP20R | HECTOR_WATCH_1_TP20R | Test pad |  |  |  |  |  |  |  |  |  |  |  |  |  |  |  |  |  |  |  | 2
TP_VREG | HECTOR_WATCH_1_TPTP20R | HECTOR_WATCH_1_TPTP20R | HECTOR_WATCH_1_TP20R | Test pad |  |  |  |  |  |  |  |  |  |  |  |  |  |  |  |  |  |  |  | 2
U1 | NORDIC_NRF_4_NRF52840_QF | NORDIC_NRF_4_NRF52840_QF | NORDIC_NRF_4_AQFN50P700X700X85_HS-74N | nRF52840
U3 | ESP32_C6_LIBRARY_MAX17048G+T10 | ESP32_C6_LIBRARY_MAX17048G+T10 | ESP32_C6_LIBRARY_SON50P200X200X80-9N | Check availability |  |  | In Stock | https://www.snapeda.com/parts/MAX17048G+T10/Analog+Devices/view-part/?ref=eda |  | 3µA 1-Cell/2-Cell Fuel Gauge with ModelGauge |  |  |  |  |  |  |  | Analog Devices |  |  |  | MAX17048G+T10 | TDFN-8 Maxim |  | None |  | https://www.snapeda.com/api/url_track_click_mouser/?unipart_id=329239&manufacturer=Analog Devices&part_name=MAX17048G+T10&search_term=None | https://www.snapeda.com/parts/MAX17048G+T10/Analog+Devices/view-part/?ref=snap
X1 | 32MHz | NORDIC_NRF_XTAL_32MHZ | NORDIC_NRF_BT-XTAL_2016_N
X2 | 32.768kHz | NORDIC_NRF_1_XTAL_32KHZ | NORDIC_NRF_1_XTAL_3215_N

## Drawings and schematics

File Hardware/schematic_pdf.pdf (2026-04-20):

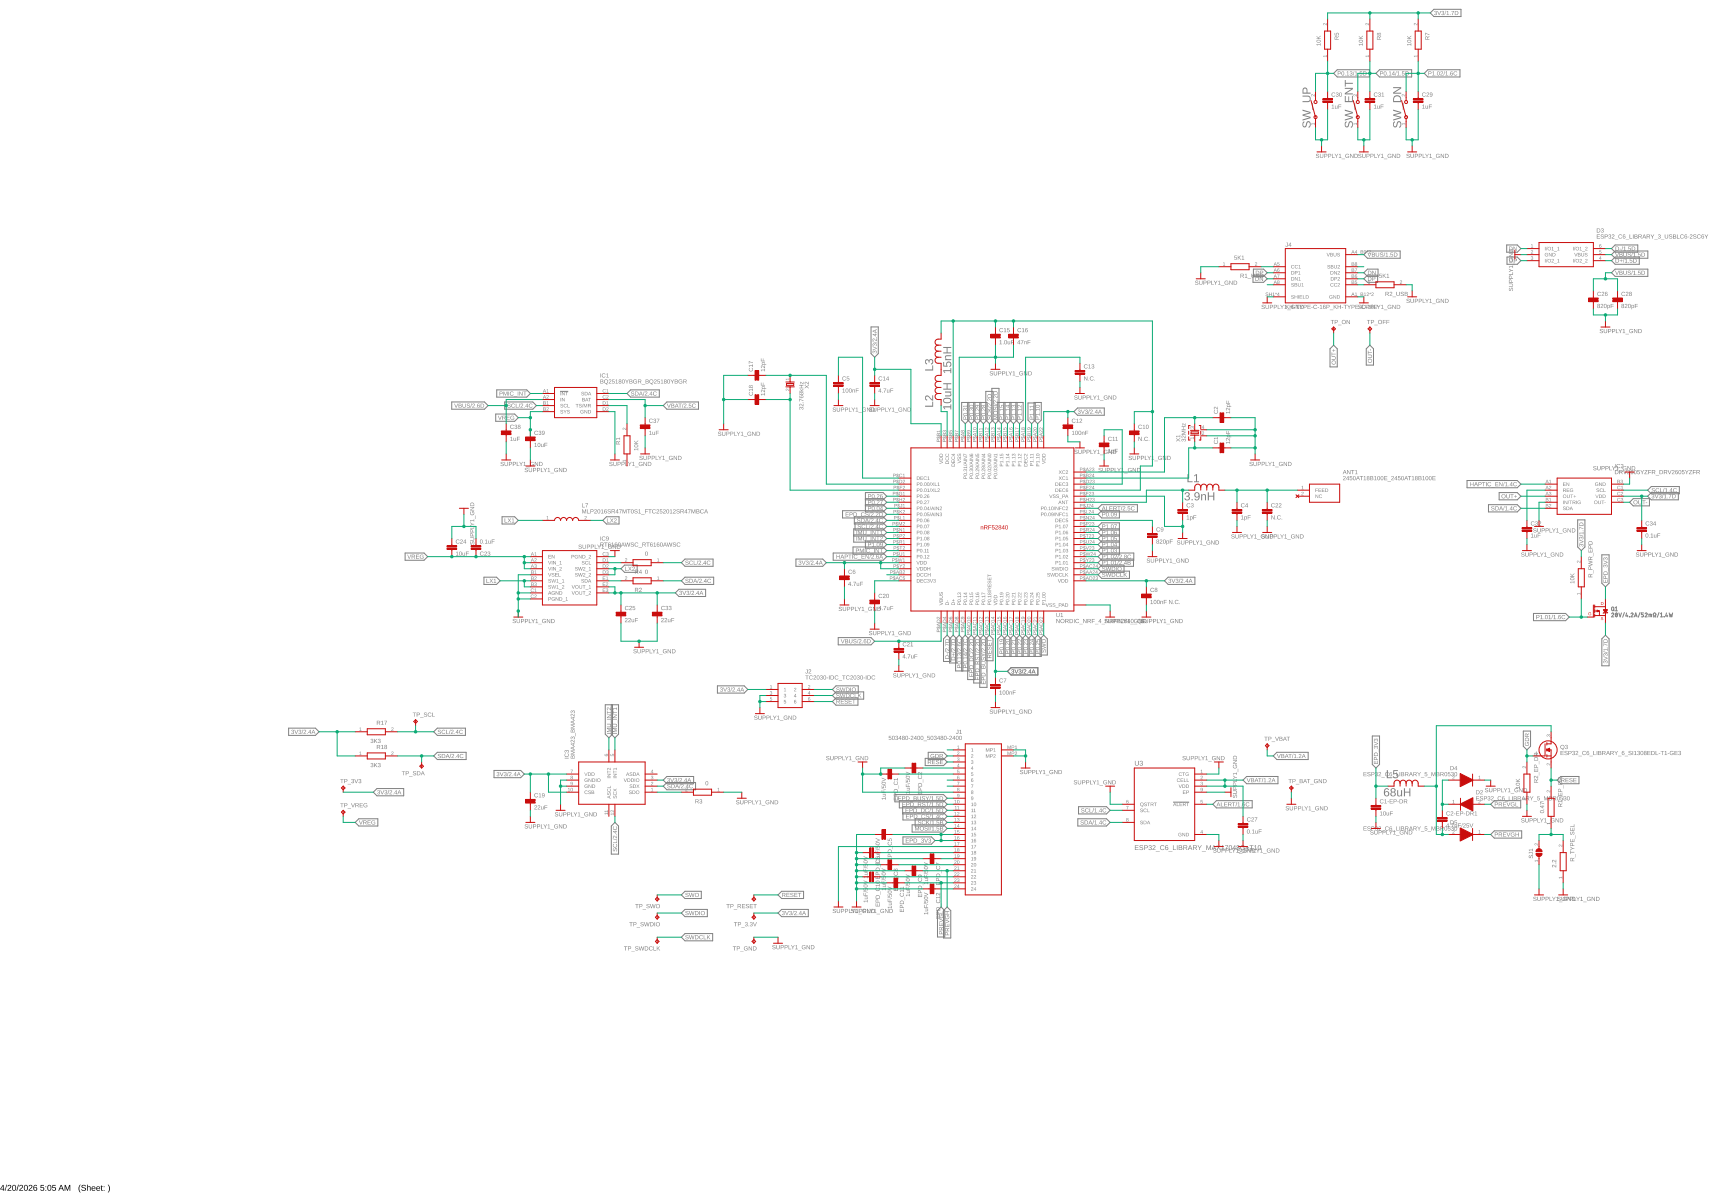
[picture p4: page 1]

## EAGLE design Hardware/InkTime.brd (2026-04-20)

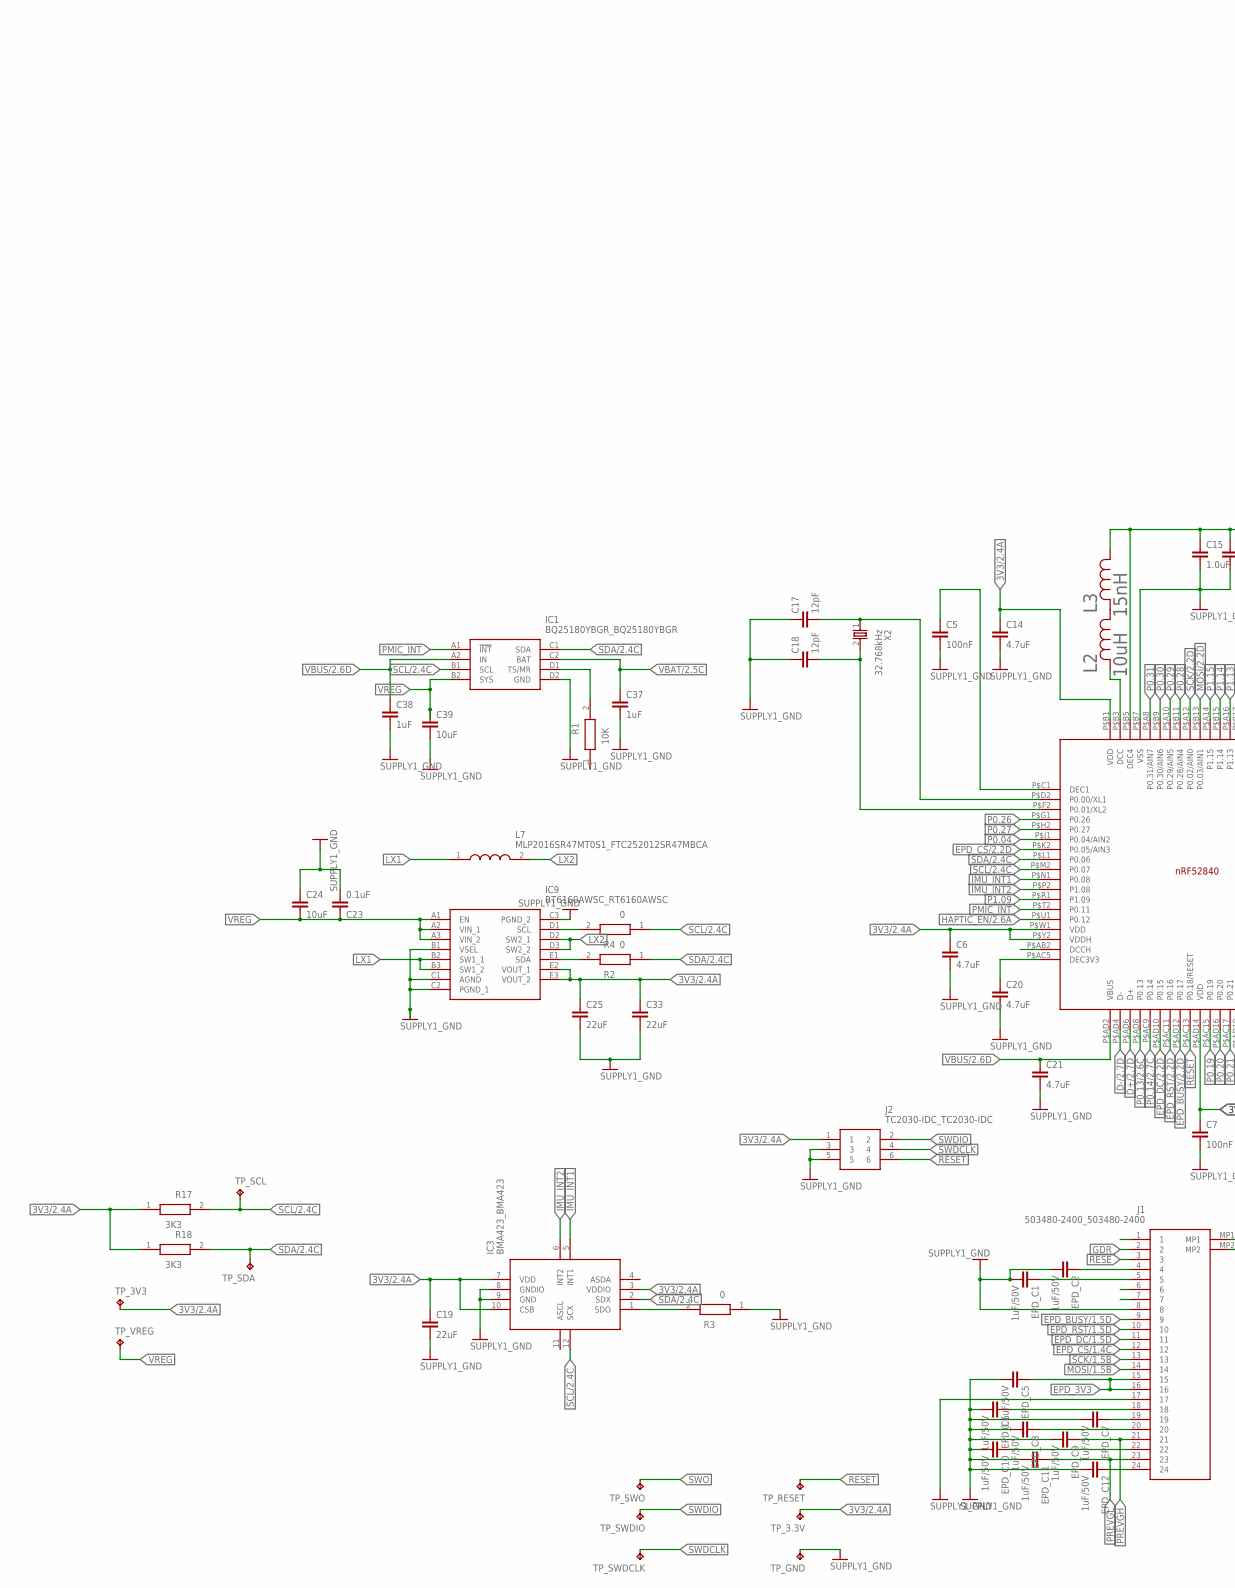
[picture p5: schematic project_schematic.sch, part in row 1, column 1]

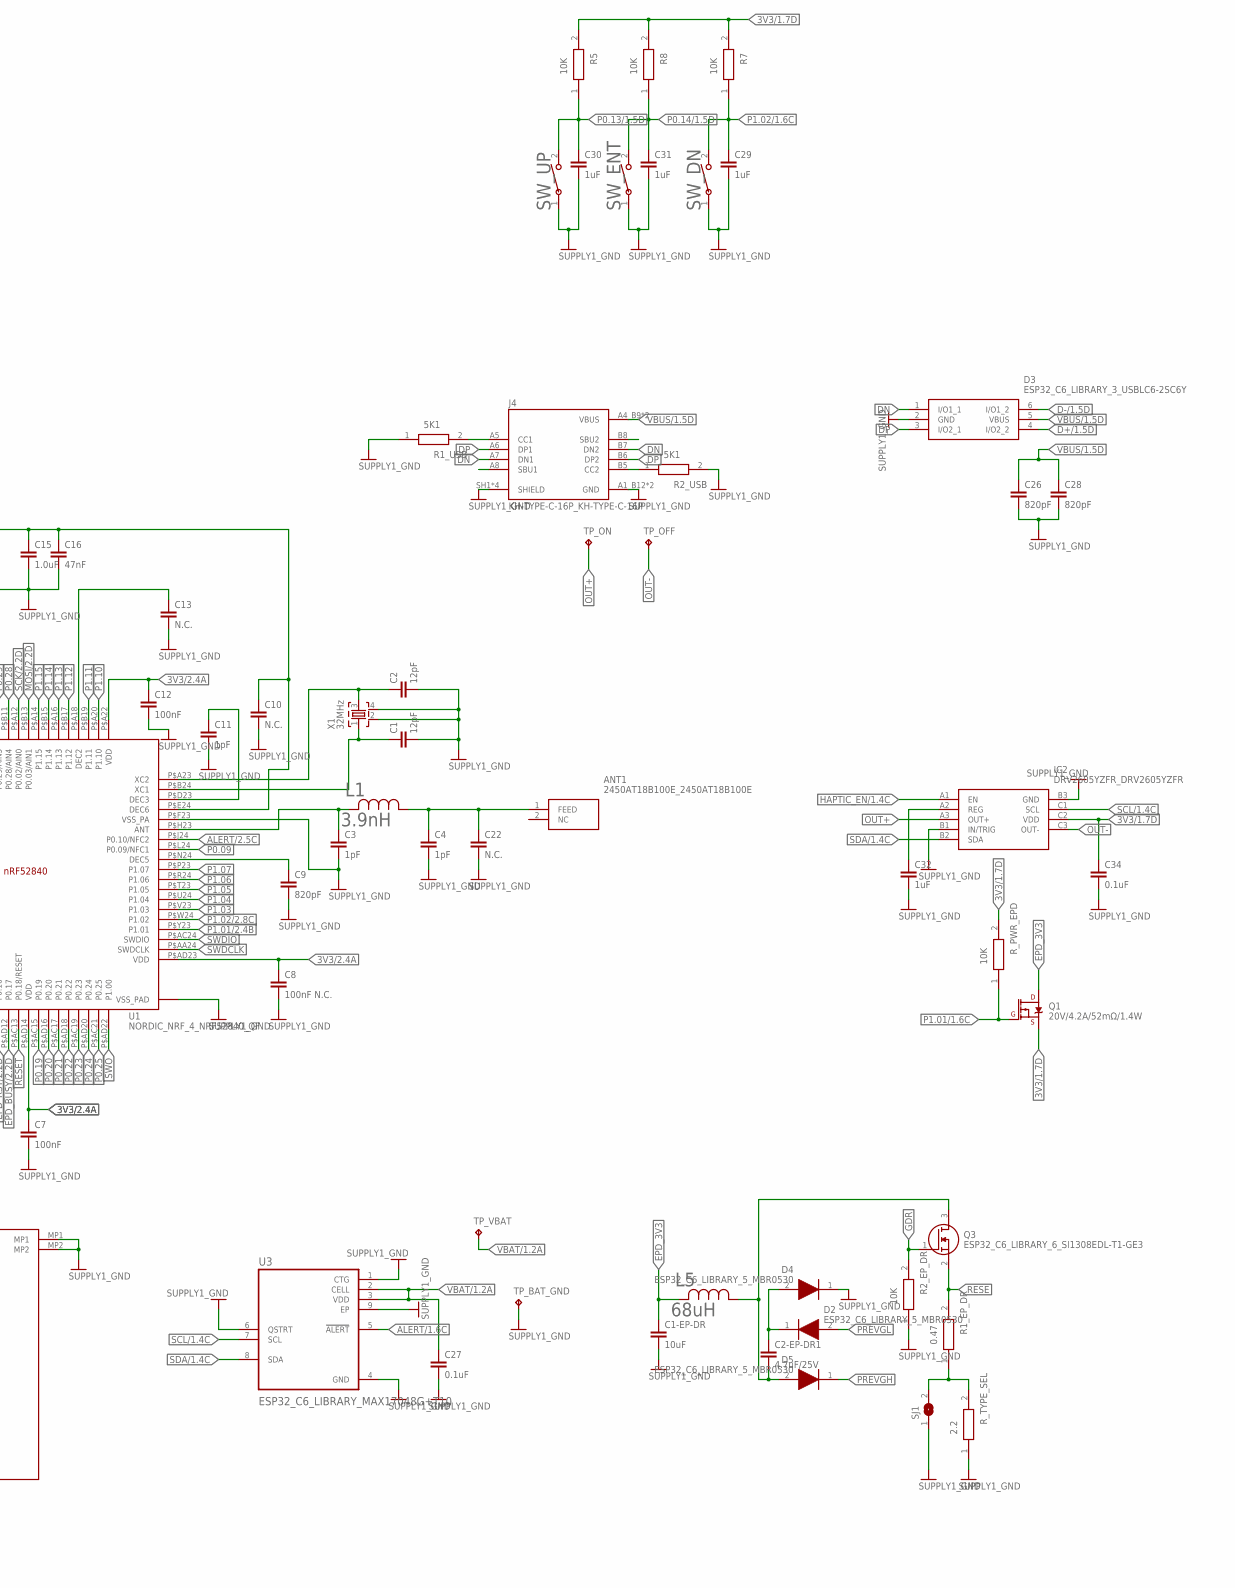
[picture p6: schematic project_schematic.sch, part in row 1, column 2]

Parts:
ANT1: 2450AT18B100E_2450AT18B100E; 2450AT18B100E_ANTC3216X140N
C1, C2, C17, C18: 12pF; ESP32_C6_LIBRARY_1_ESP32_WROVER_EAGLE-LTSPICE_C0402
C1-EP-DR, C24, C39: 10uF; ESP32_C6_LIBRARY_1_ESP32_WROVER_EAGLE-LTSPICE_C0402
C2-EP-DR1: 4.7uF/25V; ESP32_C6_LIBRARY_1_ESP32_WROVER_EAGLE-LTSPICE_C0402
C3, C4, C11: 1pF; ESP32_C6_LIBRARY_1_ESP32_WROVER_EAGLE-LTSPICE_C0402
C5, C7, C12: 100nF; ESP32_C6_LIBRARY_1_ESP32_WROVER_EAGLE-LTSPICE_C0402
C6, C14, C20, C21: 4.7uF; ESP32_C6_LIBRARY_1_ESP32_WROVER_EAGLE-LTSPICE_C0402
C8: 100nF N.C.; ESP32_C6_LIBRARY_1_ESP32_WROVER_EAGLE-LTSPICE_C0402
C9, C26, C28: 820pF; ESP32_C6_LIBRARY_1_ESP32_WROVER_EAGLE-LTSPICE_C0402
C10, C13, C22: N.C.; ESP32_C6_LIBRARY_1_ESP32_WROVER_EAGLE-LTSPICE_C0402
C15: 1.0uF; ESP32_C6_LIBRARY_1_ESP32_WROVER_EAGLE-LTSPICE_C0402
C16: 47nF; ESP32_C6_LIBRARY_1_ESP32_WROVER_EAGLE-LTSPICE_C0402
C19, C25, C33: 22uF; ESP32_C6_LIBRARY_1_ESP32_WROVER_EAGLE-LTSPICE_C0402
C23, C27, C34: 0.1uF; ESP32_C6_LIBRARY_1_ESP32_WROVER_EAGLE-LTSPICE_C0402
C29, C30, C31, C32, C37, C38: 1uF; ESP32_C6_LIBRARY_1_ESP32_WROVER_EAGLE-LTSPICE_C0402
D2, D4, D5: ESP32_C6_LIBRARY_5_MBR0530; ESP32_C6_LIBRARY_5_SOD3716X135N
D3: ESP32_C6_LIBRARY_3_USBLC6-2SC6Y; ESP32_C6_LIBRARY_3_SOT95P280X145-6N
EPD_C1, EPD_C2, EPD_C6, EPD_C7, EPD_C8, EPD_C9, EPD_C10, EPD_C11, EPD_C12: 1uF/50V; ESP32_C6_LIBRARY_1_ESP32_WROVER_EAGLE-LTSPICE_C0402
EPD_C5: 0.1uF/50V; ESP32_C6_LIBRARY_1_ESP32_WROVER_EAGLE-LTSPICE_C0402
IC1: BQ25180YBGR_BQ25180YBGR; BQ25180YBGR_BGA8C40P2X4_100X155X50
IC2: DRV2605YZFR_DRV2605YZFR; DRV2605YZFR_BGA9C50P3X3_144X144X62
IC3: BMA423_BMA423
IC9: RT6160AWSC_RT6160AWSC; RT6160AWSC_BGA15C40P3X5_140X230X60
J1: 503480-2400_503480-2400; 503480-2400_5034802400
J2: TC2030-IDC_TC2030-IDC; TC2030-IDC_TC2030IDC
J4: KH-TYPE-C-16P_KH-TYPE-C-16P; KH-TYPE-C-16P_KINGHELM_KH-TYPE-C-16P
L1: 3.9nH; ESP32_C6_LIBRARY_2_IND_4828-WE-TPC_WRE
L2: 10uH; ESP32_C6_LIBRARY_2_IND_4828-WE-TPC_WRE
L3: 15nH; ESP32_C6_LIBRARY_2_IND_4828-WE-TPC_WRE
L5: 68uH; ESP32_C6_LIBRARY_2_IND_4828-WE-TPC_WRE
L7: MLP2016SR47MT0S1_FTC252012SR47MBCA; MLP2016SR47MT0S1_INDC2016X100N
Q1: 20V/4.2A/52mΩ/1.4W; ESP32_C6_LIBRARY_4_ESP32_C6_LIBRARY_4_ESP32_C6_LIBRARY_4_ES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
Q3: ESP32_C6_LIBRARY_6_SI1308EDL-T1-GE3; ESP32_C6_LIBRARY_6_SOT65P210X110-3N
R1, R2_EP_DR, R5, R7, R8: 10K; CPF0201D7K68C1_0201
R1_EP_DR: 0.47; CPF0201D7K68C1_0201
R1_USB, R2_USB: 5K1; CPF0201D7K68C1_0201
R2, R3, R4: 0; CPF0201D7K68C1_0201
R17, R18: 3K3; CPF0201D7K68C1_0201
R_PWR_EPD: 10K; CPF0201D7K68C1_0201
R_TYPE_SEL: 2.2; CPF0201D7K68C1_0201
SJ1: ESP32_C6_LIBRARY_7_JUMPER_SJ
SW_DN: 2025-10-22_07-23-44_LIBRARY_EVP-AKE31ASW_EVP-AKE3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; 2025-10-22_07-23-44_LIBRARY_SW_EVP-AKE31A_PAN
SW_ENT: 2025-10-22_07-23-44_LIBRARY_EVP-AKE31ASW_EVP-AKE3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; 2025-10-22_07-23-44_LIBRARY_SW_EVP-AKE31A_PAN
SW_UP: 2025-10-22_07-23-44_LIBRARY_EVP-AKE31ASW_EVP-AKE3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; 2025-10-22_07-23-44_LIBRARY_SW_EVP-AKE31A_PAN
TP_3.3V, TP_3V3: HECTOR_WATCH_1_TPTP20R; HECTOR_WATCH_1_TP20R
TP_BAT_GND: HECTOR_WATCH_1_TPTP20R; HECTOR_WATCH_1_TP20R
TP_GND: HECTOR_WATCH_1_TPTP20R; HECTOR_WATCH_1_TP20R
TP_OFF: HECTOR_WATCH_1_TPTP20R; HECTOR_WATCH_1_TP20R
TP_ON: HECTOR_WATCH_1_TPTP20R; HECTOR_WATCH_1_TP20R
TP_RESET: HECTOR_WATCH_1_TPTP20R; HECTOR_WATCH_1_TP20R
TP_SCL: HECTOR_WATCH_1_TPTP20R; HECTOR_WATCH_1_TP20R
TP_SDA: HECTOR_WATCH_1_TPTP20R; HECTOR_WATCH_1_TP20R
TP_SWDCLK: HECTOR_WATCH_1_TPTP20R; HECTOR_WATCH_1_TP20R
TP_SWDIO: HECTOR_WATCH_1_TPTP20R; HECTOR_WATCH_1_TP20R
TP_SWO: HECTOR_WATCH_1_TPTP20R; HECTOR_WATCH_1_TP20R
TP_VBAT: HECTOR_WATCH_1_TPTP20R; HECTOR_WATCH_1_TP20R
TP_VREG: HECTOR_WATCH_1_TPTP20R; HECTOR_WATCH_1_TP20R
U1: NORDIC_NRF_4_NRF52840_QF; NORDIC_NRF_4_AQFN50P700X700X85_HS-74N
U3: ESP32_C6_LIBRARY_MAX17048G+T10; ESP32_C6_LIBRARY_SON50P200X200X80-9N
X1: 32MHz; NORDIC_NRF_BT-XTAL_2016_N
X2: 32.768kHz; NORDIC_NRF_1_XTAL_3215_N

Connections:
3V3/1.7D: C34.1, IC2.C2 (VDD), Q1.2 (S), R5.2, R7.2, R8.2, R_PWR_EPD.2
3V3/2.4A: C6.1, C7.1, C8.1, C12.1, C14.1, C19.1, C25.1, C33.1, IC3.3 (VDDIO), IC3.7 (VDD), IC3.10 (CSB), IC9.E2 (VOUT_1), IC9.E3 (VOUT_2), J2.1, R17.1, R18.1, TP_3.3V.TP, TP_3V3.TP, U1.P$A22 (VDD), U1.P$AD14 (VDD), U1.P$AD23 (VDD), U1.P$B1 (VDD), U1.P$W1 (VDD), U1.P$Y2 (VDDH)
ALERT/1.6C: U3.5 (!ALERT)
ALERT/2.5C: U1.P$J24 (P0.10/NFC2)
D+/1.5D: D3.4 (I/O2_2)
D+/2.7D: U1.P$AD6 (D+)
D-/1.5D: D3.6 (I/O1_2)
D-/2.7D: U1.P$AD4 (D-)
DN: D3.1 (I/O1_1), J4.A7 (DN1), J4.B7 (DN2)
DP: D3.3 (I/O2_1), J4.A6 (DP1), J4.B6 (DP2)
EPD_3V3: C1-EP-DR.1, EPD_C5.1, J1.15, J1.16, L5.2, Q1.3 (D)
EPD_BUSY/1.5D: J1.9
EPD_BUSY/2.2D: U1.P$AD12 (P0.17)
EPD_CS/1.4C: J1.12
EPD_CS/2.2D: U1.P$K2 (P0.05/AIN3)
EPD_DC/1.5D: J1.11
EPD_DC/2.2D: U1.P$AD10 (P0.15)
EPD_RST/1.5D: J1.10
EPD_RST/2.2D: U1.P$AC11 (P0.16)
GDR: J1.2, Q3.1 (G), R2_EP_DR.2
GND: C1.2, C1-EP-DR.2, C2.2, C3.2, C4.2, C5.2, C6.2, C7.2, C8.2, C9.2, C10.2, C11.2, C12.2, C13.2, C14.2, C15.2, C16.2, C17.1, C18.1, C19.2, C20.2, C21.2, C22.2, C23.2, C24.1, C25.2, C26.2, C27.2, C28.2, C29.2, C30.2, C31.2, C32.2, C33.2, C34.2, C37.2, C38.2, C39.2, D3.2 (GND), D4.1 (K), EPD_C1.2, EPD_C2.2, EPD_C5.2, EPD_C6.2, EPD_C7.2, EPD_C8.2, EPD_C9.2, EPD_C10.2, EPD_C11.2, EPD_C12.2, IC1.D2 (GND), IC2.B1 (IN/TRIG), IC2.B3 (GND), IC3.8 (GNDIO), IC3.9 (GND), IC9.B1 (VSEL), IC9.C1 (AGND), IC9.C2 (PGND_1), IC9.C3 (PGND_2), J1.8, J1.17, J1.MP1, J1.MP2, J2.3, J2.5, J4.A1_B12 (GND), J4.A12_B1 (GND), J4.SH1 (SHIELD), J4.SH2 (SHIELD), J4.SH3 (SHIELD), J4.SH4 (SHIELD), R1_USB.1, R2_EP_DR.1, R2_USB.2, R3.1, R_TYPE_SEL.1, SJ1.1, SW_DN.1, SW_ENT.1, SW_UP.1, TP_BAT_GND.TP, TP_GND.TP, U1.P$74 (VSS_PAD), U1.P$75 (VSS_PAD), U1.P$76 (VSS_PAD), U1.P$77 (VSS_PAD), U1.P$78 (VSS_PAD), U1.P$79 (VSS_PAD), U1.P$80 (VSS_PAD), U1.P$81 (VSS_PAD), U1.P$82 (VSS_PAD), U1.P$83 (VSS_PAD), U1.P$84 (VSS_PAD), U1.P$85 (VSS_PAD), U1.P$86 (VSS_PAD), U1.P$87 (VSS_PAD), U1.P$88 (VSS_PAD), U1.P$89 (VSS_PAD), U1.P$90 (VSS_PAD), U1.P$B7 (VSS), U1.P$F23 (VSS_PA), U3.1 (CTG), U3.4 (GND), U3.6 (QSTRT), U3.9 (EP), X1.2, X1.4
HAPTIC_EN/1.4C: IC2.A1 (EN)
HAPTIC_EN/2.6A: U1.P$U1 (P0.12)
IMU_INT1: IC3.5 (INT1), U1.P$N1 (P0.08)
IMU_INT2: IC3.6 (INT2), U1.P$P2 (P1.08)
LX1: IC9.B2 (SW1_1), IC9.B3 (SW1_2), L7.1
LX2: IC9.D2 (SW2_1), IC9.D3 (SW2_2), L7.2
MOSI/1.5B: J1.14
MOSI/2.2D: U1.P$A14 (P1.15)
unnamed: IC9.D1 (SCL), R4.2
unnamed: IC9.E1 (SDA), R2.2
unnamed: L2.2, U1.P$B3 (DCC)
unnamed: L2.1, L3.2
unnamed: C17.2, U1.P$D2 (P0.00/XL1), X2.1
unnamed: IC1.D1 (TS/MR), R1.2
unnamed: IC3.1 (SDO), R3.2
unnamed: ANT1.1 (FEED), C4.1, C22.1, L1.1
unnamed: C3.1, L1.2, U1.P$H23 (ANT)
unnamed: C1.1, U1.P$B24 (XC1), X1.1
unnamed: C2.1, U1.P$A23 (XC2), X1.3
unnamed: J4.A5 (CC1), R1_USB.2
unnamed: EPD_C2.1, J1.4
unnamed: EPD_C1.1, J1.5
unnamed: C13.1, U1.P$A18 (DEC2)
unnamed: C2-EP-DR1.2, D5.2 (A), L5.1, Q3.3 (D)
unnamed: C2-EP-DR1.1, D2.1 (K), D4.2 (A)
unnamed: C11.1, U1.P$D23 (DEC3)
unnamed: C10.1, C15.1, C16.1, L3.1, U1.P$B5 (DEC4), U1.P$E24 (DEC6)
unnamed: J4.B5 (CC2), R2_USB.1
unnamed: C9.1, U1.P$N24 (DEC5)
unnamed: C32.1, IC2.A2 (REG)
unnamed: EPD_C6.1, J1.18
unnamed: EPD_C7.1, J1.19
unnamed: EPD_C8.1, J1.20
unnamed: EPD_C10.1, J1.22
unnamed: R1_EP_DR.1, R_TYPE_SEL.2, SJ1.2
unnamed: EPD_C12.1, J1.24
unnamed: C20.1, U1.P$AC5 (DEC3V3)
unnamed: C18.2, U1.P$F2 (P0.01/XL2), X2.2
unnamed: C5.1, U1.P$C1 (DEC1)
OUT+: IC2.A3 (OUT+), TP_ON.TP
OUT-: IC2.C3 (OUT-), TP_OFF.TP
P0.04: U1.P$J1 (P0.04/AIN2)
P0.09: U1.P$L24 (P0.09/NFC1)
P0.13/1.5D: C30.1, R5.1, SW_UP.2
P0.13/2.6C: U1.P$AD8 (P0.13)
P0.14/1.5D: C31.1, R8.1, SW_ENT.2
P0.14/2.7C: U1.P$AC9 (P0.14)
P0.19: U1.P$AC15 (P0.19)
P0.20: U1.P$AD16 (P0.20)
P0.21: U1.P$AC17 (P0.21)
P0.22: U1.P$AD18 (P0.22)
P0.23: U1.P$AC19 (P0.23)
P0.24: U1.P$AD20 (P0.24)
P0.25: U1.P$AC21 (P0.25)
P0.26: U1.P$G1 (P0.26)
P0.27: U1.P$H2 (P0.27)
P0.28: U1.P$A12 (P0.02/AIN0)
P0.29: U1.P$B11 (P0.28/AIN4)
P0.30: U1.P$A10 (P0.29/AIN5)
P0.31: U1.P$B9 (P0.30/AIN6)
P1.01/1.6C: Q1.1 (G), R_PWR_EPD.1
P1.01/2.4B: U1.P$Y23 (P1.01)
P1.02/1.6C: C29.1, R7.1, SW_DN.2
P1.02/2.8C: U1.P$W24 (P1.02)
P1.03: U1.P$V23 (P1.03)
P1.04: U1.P$U24 (P1.04)
P1.05: U1.P$T23 (P1.05)
P1.06: U1.P$R24 (P1.06)
P1.07: U1.P$P23 (P1.07)
P1.09: U1.P$R1 (P1.09)
P1.10: U1.P$A20 (P1.10)
P1.11: U1.P$B19 (P1.11)
P1.12: U1.P$B17 (P1.12)
P1.14: U1.P$A16 (P1.13)
P1.15: U1.P$B15 (P1.14)
PMIC_INT: IC1.A1 (!INT), U1.P$T2 (P0.11)
PREVGH: D5.1 (K), EPD_C9.1, J1.21
PREVGL: D2.2 (A), EPD_C11.1, J1.23
RESE: J1.3, Q3.2 (S), R1_EP_DR.2
RESET: J2.6, TP_RESET.TP, U1.P$AC13 (P0.18/RESET)
SCK/1.5B: J1.13
SCK/2.2D: U1.P$B13 (P0.03/AIN1)
SCL/1.4C: IC2.C1 (SCL), U3.7 (SCL)
SCL/2.4C: IC1.B1 (SCL), IC3.12 (SCX), R4.1, R17.2, TP_SCL.TP, U1.P$M2 (P0.07)
SDA/1.4C: IC2.B2 (SDA), U3.8 (SDA)
SDA/2.4C: IC1.C1 (SDA), IC3.2 (SDX), R2.1, R18.2, TP_SDA.TP, U1.P$L1 (P0.06)
SWDCLK: J2.4, TP_SWDCLK.TP, U1.P$AA24 (SWDCLK)
SWDIO: J2.2, TP_SWDIO.TP, U1.P$AC24 (SWDIO)
SWO: TP_SWO.TP, U1.P$AD22 (P1.00)
VBAT/1.2A: C27.1, TP_VBAT.TP, U3.2 (CELL), U3.3 (VDD)
VBAT/2.5C: C37.1, IC1.C2 (BAT)
VBUS/1.5D: C26.1, C28.1, D3.5 (VBUS), J4.A4_B9 (VBUS), J4.A9_B4 (VBUS)
VBUS/2.6D: C21.1, C38.1, IC1.A2 (IN), U1.P$AD2 (VBUS)
VREG: C23.1, C24.2, C39.1, IC1.B2 (SYS), IC9.A1 (EN), IC9.A2 (VIN_1), IC9.A3 (VIN_2), TP_VREG.TP

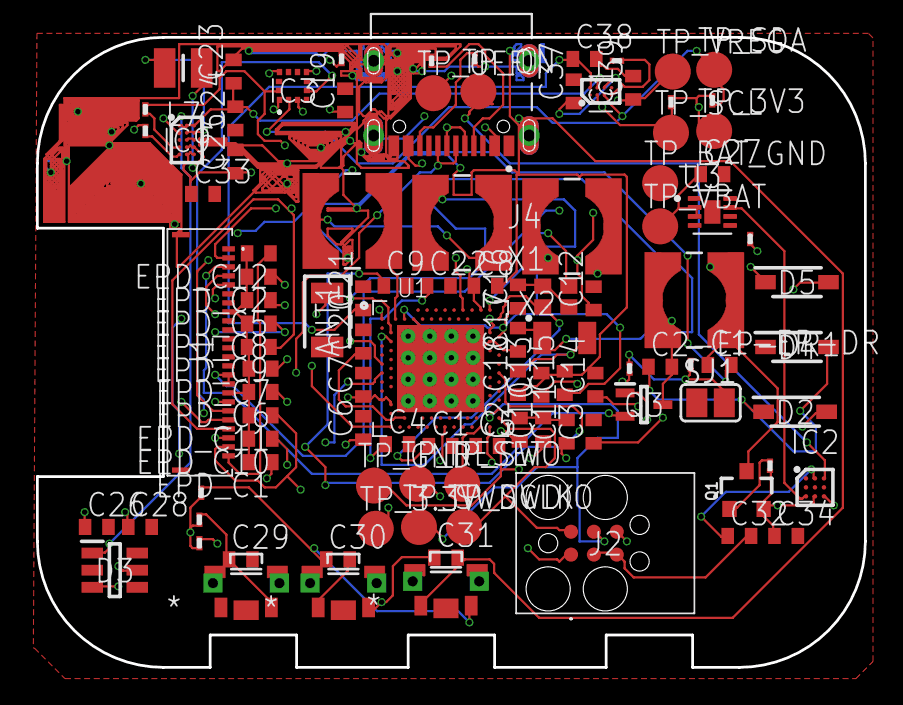
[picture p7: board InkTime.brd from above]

Board: 4 copper layers, 46.0 x 35.0 mm, 105 parts (0 on the bottom side), 65 nets.

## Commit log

2026-04-10 fisiere de pana acm
    [InkTime.brd, project_schematic.sch]
2026-04-10 added routes
    [InkTime.brd]
2026-04-20 issue solved
    [InkTime.brd, bom.csv, project_schematic.sch]

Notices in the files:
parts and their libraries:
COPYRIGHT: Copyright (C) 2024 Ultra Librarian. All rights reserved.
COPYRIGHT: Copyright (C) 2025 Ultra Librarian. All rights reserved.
